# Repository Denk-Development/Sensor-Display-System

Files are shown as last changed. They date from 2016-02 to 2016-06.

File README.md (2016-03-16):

# Sensor-Display-System
A Teensy (https://www.pjrc.com/teensy/) based system for a laser show, transmitting and displaying sensor data.

In a nutshell the whole project is about showing and logging transmitted sensor data of laser show hardware. This includes among others currents, voltages, temperatures, water flow and humidity data.

For performance reasons the system uses two Teensy 3.2 micrcontrollers (72 MHz Cortex-M4) instead of the Arduino's ATmega 328. 

This is a private project.
I've developed it for Lucien Tunger (http://www.lsd-lasershowdesign.de/).

## Testing setup
The picture shows both, Sensor- and Display-Teensy. The Sensor-Teensy isn't equipped with any peripheral devices whereas the Display-Teensy is wired up with an LCD display, a real time clock module and an SD card breakout.
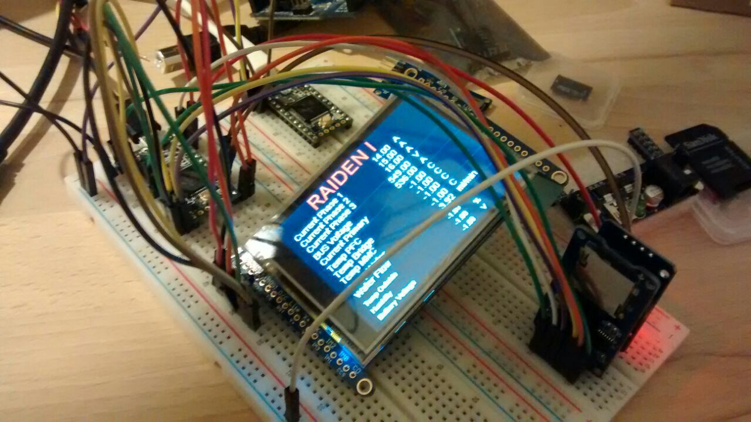
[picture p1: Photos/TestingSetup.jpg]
Testing setup image


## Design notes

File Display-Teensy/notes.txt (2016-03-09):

SD Card works only with: card.init(SPI_QUARTER_SPEED, chipSelect)
https://github.com/adafruit/Adafruit_ILI9341/blob/master/examples/spitftbitmap/spitftbitmap.ino
http://forum.arduino.cc/index.php?topic=108017.0

Use alternative time library: http://forum.arduino.cc/index.php?topic=305003.0
TimeTeensy3.ino example sketch works

Wire Real-Time Module to 3.3 V

Format SD Card not! with the Official Formatter on Mac but with the built in utilities FAT16

Arduino IDE 1.0.6

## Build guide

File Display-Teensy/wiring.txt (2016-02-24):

DISPLAY ILI9341
3-5V Vin connects to the Arduino 5V pin
GND connects to Arduino ground
CLK connects to SPI clock. On Arduino Uno/Duemilanove/328-based, thats Digital 13. On Mega's, its Digital 52 and on Leonardo/Due its ICSP-3 (See SPI Connections for more details)
MISO connects to SPI MISO. On Arduino Uno/Duemilanove/328-based, thats Digital 12. On Mega's, its Digital 50 and on Leonardo/Due its ICSP-1 (See SPI Connections for more details)
MOSI connects to SPI MOSI. On Arduino Uno/Duemilanove/328-based, thats Digital 11. On Mega's, its Digital 51 and on Leonardo/Due its ICSP-4 (See SPI Connections for more details)
CS connects to our SPI Chip Select pin. We'll be using Digital 10 but you can later change this to any pin
D/C connects to our SPI data/command select pin. We'll be using Digital 9 but you can later change this pin too.

SD CARD BREAKOUT
pin 11 = MOSI
pin 12 = MISO
pin 13 = SCK
pin 5 = CS (variable)

SENSOR TEENSY
dataLinkRX 0
dataLinkTX 1

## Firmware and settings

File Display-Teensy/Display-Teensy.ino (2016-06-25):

#include <SPI.h>

// sd card / logging
#include <SD.h>
#include <Time.h>  

// display
#include <ILI9341_t3.h>
#include <font_Arial.h>
#include <font_ArialBold.h>
#include <font_ArialItalic.h>
#include <font_ArialBoldItalic.h>

#define dataLink Serial1 // RX: 0; TX: 1

#define batteryVoltagePin A0

// display
#define TFT_DC 9
#define TFT_CS 10
#define BACKGROUND_COLOR ILI9341_BLACK
#define sensorStringsOffsetTop 30
#define sensorStringsLineHeight 15
#define unitsOffset 240
#define offsetPerHr 2

// sd card breakout
#define SD_CS 5

#define BUFFPIXEL 20

#define numberOfSensors 13
#define bytesPerSensor 4

File logFile;
char logFileName[12]; // log files have a fixed file name length of 10+1 chars ("MMDDHH.LOG")

const unsigned int millisUntilJamDetection = 50;

unsigned long lastPossibleJam = 0;
boolean jamTimerSet = false;

byte * data;
float * oldSensorValues = (float *) calloc(sizeof(float), numberOfSensors);

int dataLength, bytesAvailable, bytesAvailableAfterDelay;

long numberOfBytesAvailableLastTime = 0;

// battery voltage
int vout = 0, vin = 0;
float R1 = 47000.0, R2 = 4700.0;

// display object
ILI9341_t3 tft = ILI9341_t3(TFT_CS, TFT_DC);

String sensorNames[numberOfSensors] = { "Current Phase 1", "Current Phase 2", "Current Phase 3", "BUS Voltage", "Current Primary", "Temp PFC", "Temp Bridge", "Temp MMC", "Temp Water", "Water Flow", "Temp Outside", "Humidity", "Battery Voltage" };
String sensorUnits[numberOfSensors] = { "A", "A", "A", "V", "A", "C", "C", "C", "C", "ml/min", "C", "%", "V" };
byte sensorLineOffset[numberOfSensors] = { 0, 0, 0, offsetPerHr, offsetPerHr, 2 * offsetPerHr, 2 * offsetPerHr, 2 * offsetPerHr, 3 * offsetPerHr, 3 * offsetPerHr, 6 * offsetPerHr, 6 * offsetPerHr, 6 * offsetPerHr };

void setup() {
  pinMode(batteryVoltagePin, INPUT);
  Serial.begin(9600);
  
  // start tft
  tft.begin();
  tft.setRotation(3);
  tft.fillScreen(BACKGROUND_COLOR);
  
  // start sd card
  Serial.print("Initializing SD card...");
  if (!SD.begin(SD_CS, SPI_QUARTER_SPEED)) {
    Serial.println("SD card failed");
  }
  Serial.println("SD card ok");

  // draw logo
  bmpDraw("logo.bmp", 0, 0);
  
  Serial.println("showing logo");
  
  delay(5000); // show logo
  
  
  // initialize time module 
  // set the Time library to use Teensy 3.0's RTC to keep time
  setSyncProvider(getTeensy3Time);
  delay(100);
  if (timeStatus() != timeSet) {
    Serial.println("Unable to sync with the RTC");
  } else {
    Serial.println("RTC has set the system time");
  }
  
  
  Serial.println("showing sensor data");
  tft.fillScreen(BACKGROUND_COLOR);
  
  tft.setCursor(70, 5);
  tft.setFont(Arial_24);
  tft.setTextColor(rgb2col(255,0,0));
  tft.print("RAIDEN I");
  
  
  // print sensor names
  tft.setFont(Arial_10);
  tft.setTextColor(rgb2col(255,255,255));
  for (int i = 0; i < numberOfSensors; i++) {    
    if (i == 10) {
      tft.setFont(Arial_8);
    }
    
    int yOffset =  5 + sensorStringsOffsetTop + sensorStringsLineHeight * i + sensorLineOffset[i];
    tft.setCursor(15, yOffset);
    tft.print(sensorNames[i]);
    tft.setCursor(unitsOffset, yOffset);
    tft.print(sensorUnits[i]);
  }
  
  // draw horizontal lines
  uint16_t hLineColor = rgb2col(25,25,25);
  tft.drawFastHLine(0, 5 + sensorStringsOffsetTop + 3 * sensorStringsLineHeight - 3 + 1 * offsetPerHr, 320, hLineColor);
  tft.drawFastHLine(0, 5 + sensorStringsOffsetTop + 5 * sensorStringsLineHeight - 3 + 2 * offsetPerHr, 320, hLineColor);
  tft.drawFastHLine(0, 5 + sensorStringsOffsetTop + 8 * sensorStringsLineHeight - 3 + 3 * offsetPerHr, 320, hLineColor);
  tft.drawFastHLine(0, 5 + sensorStringsOffsetTop + 10 * sensorStringsLineHeight - 3 + 4 * offsetPerHr, 320, hLineColor);
  
  dataLength = numberOfSensors * bytesPerSensor;
  data = (byte *) malloc(sizeof(byte) * dataLength);
  
  // create log file
  String tmp = getLogFileName();
  logFileName[tmp.length()+1];
  tmp.toCharArray(logFileName, sizeof(logFileName));
  Serial.println(tmp.length());
  Serial.println(tmp);
  Serial.println(logFileName);
  logFile = SD.open(logFileName, FILE_WRITE);
  logFile.close();
  
  // check if the log file has been created successfully
  if (SD.exists(logFileName)) {
    Serial.println("log file created");
  } else {
    Serial.println("couldn't create log file");
  }
  
  
  // serial connection to sensor arduino
  dataLink.begin(58824); // Arduino 57600 is actually 58824 (https://www.pjrc.com/teensy/td_uart.html)
  // baud rates 300, 600, 1200, 2400, 4800, 9600, 14400, 19200, 28800, 31250, 38400, 57600, 115200
}

void loop() {
  // time module
  if (jamTimerSet && lastPossibleJam < millis() - millisUntilJamDetection) {
    jamTimerSet = false;
    flushDataLinkBuffer();
    Serial.println("flushed");
  }
  
  
  // check if data is currently incoming
  if (numberOfBytesAvailableLastTime != dataLink.available()) {
    jamTimerSet = false;
    Serial.println("jam timer set");
  }
  
  if (dataLink.available() > 0 && dataLink.available() % dataLength == 0) {
    jamTimerSet = false;
    
    Serial.println("data incoming");
    
    dataLink.readBytes((char *)data, dataLength);
    
    // open log file
    logFile = SD.open(logFileName, FILE_WRITE);
    logFile.print(getTimeString()); // log time
    
    tft.setFont(Arial_10);
    for (int i = 0;  i < numberOfSensors; i++) {    
      if (i == 10) {
        tft.setFont(Arial_8);
      }
      
      float * sensorValue = (float *) & data[i * bytesPerSensor];
      float val = * sensorValue;
      
      if (i == 12) { // battery voltage
        val = getBatteryVoltage();
      }
      
      logFile.print(",");
      logFile.print(val);
      
      Serial.println("Sensor " + String(i) + ": " + String(val));
      
      // write only to the screen when values have changed
      if (oldSensorValues[i] != val) {
        String valString = floatToDisplayString(val);
        byte valStringLength = valString.length();
        byte minusSignOffset = (valString.charAt(0) == '-') ? 4 : 0;
        byte cursorY = 5 + sensorStringsOffsetTop + sensorStringsLineHeight * i + sensorLineOffset[i];
        tft.setCursor(5 + 160 + (8 - valStringLength) * 9 + minusSignOffset, cursorY);
        
        // hide old value by drawing a rectangle (x, y, width, height)
        tft.fillRect(160, cursorY, 75, sensorStringsLineHeight - 4, BACKGROUND_COLOR); // clear row
        tft.print(valString);
        
        oldSensorValues[i] = val;
      }
    }
    
    // log file end line
    logFile.println();
    logFile.close(); // save changes
  }
  
  // possibly invalid data in the buffer
  else if (!jamTimerSet && dataLink.available() != 0) {
    lastPossibleJam = millis();
    jamTimerSet = true;
  }
}

void flushDataLinkBuffer() {
  Serial.println("flushed");
  while (dataLink.available()) {
    dataLink.read();
  }
}

String floatToDisplayString(float f) {
  String s = String(f);
  // add leading spaces
  /*while (s.length() < 7) {
    s = " " + s;
  }*/
  return s; 
}


uint16_t rgb2col(uint8_t r, uint8_t g, uint8_t b) {
  return ((r & 0xF8) << 8) | ((g & 0xFC) << 3) | (b >> 3);
}


// time module code

String getTimeString() {
  return addLeadingZeros(year(), 4) + "." + addLeadingZeros(month(), 2) + "." + addLeadingZeros(day(), 2) + " " + addLeadingZeros(hour(), 2) + ":" + addLeadingZeros(minute(), 2) + ":" + addLeadingZeros(second(), 2);
}

String getLogFileName() {
  return addLeadingZeros(month(), 2) + addLeadingZeros(day(), 2) + addLeadingZeros(hour(), 2) + ".LOG";  
}

time_t getTeensy3Time()
{
  return Teensy3Clock.get();
}

/*  code to process time sync messages from the serial port   */
#define TIME_HEADER  "T"   // Header tag for serial time sync message

unsigned long processSyncMessage() {
  unsigned long pctime = 0L;
  const unsigned long DEFAULT_TIME = 1357041600; // Jan 1 2013 

  if(Serial.find(TIME_HEADER)) {
     pctime = Serial.parseInt();
     return pctime;
     if( pctime < DEFAULT_TIME) { // check the value is a valid time (greater than Jan 1 2013)
       pctime = 0L; // return 0 to indicate that the time is not valid
     }
  }
  return pctime;
}

void printDigits(int digits){
  // utility function for digital clock display: prints preceding colon and leading 0
  Serial.print(":");
  if(digits < 10)
    Serial.print('0');
  Serial.print(digits);
}

String addLeadingZeros(int x, int digits) {
  String str = String(x);
  while (str.length() < digits) {
    str = '0' + str;
  }
  return str;
}

// battery voltage
long readVcc() {
  long result;
  ADMUX = _BV(REFS0) | _BV(MUX3) | _BV(MUX2) | _BV(MUX1);
  delay(2);
  ADCSRA |= _BV(ADSC);
  while (bit_is_set(ADCSRA,ADSC));
  result = ADCL;
  result |= ADCH<<8;
  result = 1126400L / result;
  return result;
}

int getBatteryVoltage() {
  vout = (analogRead(batteryVoltagePin) * readVcc() / 1000) / 1024.0;
  vin = vout / (R2/(R1+R2));
  return vin;
}



// draw bitmap code


// This function opens a Windows Bitmap (BMP) file and
// displays it at the given coordinates.  It's sped up
// by reading many pixels worth of data at a time
// (rather than pixel by pixel).  Increasing the buffer
// size takes more of the Arduino's precious RAM but
// makes loading a little faster.  20 pixels seems a
// good balance.

#define BUFFPIXEL 20

void bmpDraw(char *filename, uint8_t x, uint16_t y) {

  File     bmpFile;
  int      bmpWidth, bmpHeight;   // W+H in pixels
  uint8_t  bmpDepth;              // Bit depth (currently must be 24)
  uint32_t bmpImageoffset;        // Start of image data in file
  uint32_t rowSize;               // Not always = bmpWidth; may have padding
  uint8_t  sdbuffer[3*BUFFPIXEL]; // pixel buffer (R+G+B per pixel)
  uint8_t  buffidx = sizeof(sdbuffer); // Current position in sdbuffer
  boolean  goodBmp = false;       // Set to true on valid header parse
  boolean  flip    = true;        // BMP is stored bottom-to-top
  int      w, h, row, col;
  uint8_t  r, g, b;
  uint32_t pos = 0, startTime = millis();

  if((x >= tft.width()) || (y >= tft.height())) return;

  Serial.println();
  Serial.print(F("Loading image '"));
  Serial.print(filename);
  Serial.println('\'');

  // Open requested file on SD card
  if ((bmpFile = SD.open(filename)) == NULL) {
    Serial.print(F("file not found"));
    return;
  }

  // Parse BMP header
  if(read16(bmpFile) == 0x4D42) { // BMP signature
    Serial.print(F("File size: ")); Serial.println(read32(bmpFile));
    (void)read32(bmpFile); // Read & ignore creator bytes
    bmpImageoffset = read32(bmpFile); // Start of image data
    Serial.print(F("Image Offset: ")); Serial.println(bmpImageoffset, DEC);
    // Read DIB header
    Serial.print(F("Header size: ")); Serial.println(read32(bmpFile));
    bmpWidth  = read32(bmpFile);
    bmpHeight = read32(bmpFile);
    if(read16(bmpFile) == 1) { // # planes -- must be '1'
      bmpDepth = read16(bmpFile); // bits per pixel
      Serial.print(F("Bit Depth: ")); Serial.println(bmpDepth);
      if((bmpDepth == 24) && (read32(bmpFile) == 0)) { // 0 = uncompressed

        goodBmp = true; // Supported BMP format -- proceed!
        Serial.print(F("Image size: "));
        Serial.print(bmpWidth);
        Serial.print('x');
        Serial.println(bmpHeight);

        // BMP rows are padded (if needed) to 4-byte boundary
        rowSize = (bmpWidth * 3 + 3) & ~3;

        // If bmpHeight is negative, image is in top-down order.
        // This is not canon but has been observed in the wild.
        if(bmpHeight < 0) {
          bmpHeight = -bmpHeight;
          flip      = false;
        }

        // Crop area to be loaded
        w = bmpWidth;
        h = bmpHeight;
        if((x+w-1) >= tft.width())  w = tft.width()  - x;
        if((y+h-1) >= tft.height()) h = tft.height() - y;

        // Set TFT address window to clipped image bounds
        tft.setAddrWindow(x, y, x+w-1, y+h-1);

        for (row=0; row<h; row++) { // For each scanline...

          // Seek to start of scan line.  It might seem labor-
          // intensive to be doing this on every line, but this
          // method covers a lot of gritty details like cropping
          // and scanline padding.  Also, the seek only takes
          // place if the file position actually needs to change
          // (avoids a lot of cluster math in SD library).
          if(flip) // Bitmap is stored bottom-to-top order (normal BMP)
            pos = bmpImageoffset + (bmpHeight - 1 - row) * rowSize;
          else     // Bitmap is stored top-to-bottom
            pos = bmpImageoffset + row * rowSize;
          if(bmpFile.position() != pos) { // Need seek?
            bmpFile.seek(pos);
            buffidx = sizeof(sdbuffer); // Force buffer reload
          }

          for (col=0; col<w; col++) { // For each pixel...
            // Time to read more pixel data?
            if (buffidx >= sizeof(sdbuffer)) { // Indeed
              bmpFile.read(sdbuffer, sizeof(sdbuffer));
              buffidx = 0; // Set index to beginning
            }

            // Convert pixel from BMP to TFT format, push to display
            b = sdbuffer[buffidx++];
            g = sdbuffer[buffidx++];
            r = sdbuffer[buffidx++];
            tft.pushColor(tft.color565(r,g,b));
          } // end pixel
        } // end scanline
        Serial.print(F("Loaded in "));
        Serial.print(millis() - startTime);
        Serial.println(" ms");
      } // end goodBmp
    }
  }

  bmpFile.close();
  if(!goodBmp) Serial.println(F("BMP format not recognized."));
}

// These read 16- and 32-bit types from the SD card file.
// BMP data is stored little-endian, Arduino is little-endian too.
// May need to reverse subscript order if porting elsewhere.

uint16_t read16(File &f) {
  uint16_t result;
  ((uint8_t *)&result)[0] = f.read(); // LSB
  ((uint8_t *)&result)[1] = f.read(); // MSB
  return result;
}

uint32_t read32(File &f) {
  uint32_t result;
  ((uint8_t *)&result)[0] = f.read(); // LSB
  ((uint8_t *)&result)[1] = f.read();
  ((uint8_t *)&result)[2] = f.read();
  ((uint8_t *)&result)[3] = f.read(); // MSB
  return result;
}

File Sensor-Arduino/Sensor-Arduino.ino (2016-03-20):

#include <SoftwareSerial.h>
#include <Wire.h>
#include <Adafruit_MCP9808.h>
#include <Adafruit_HTU21DF.h>

// pinning
// Serial TX Pin 0
// Serial RX Pin 1
#define flowSensorPin 2
#define dataLinkRX 3
#define dataLinkTX 4

#define currentPhase1Pin A0
#define currentPhase2Pin A1
#define currentPhase3Pin A2
// #define flowCurrrentPin A5 
#define busVoltagePin A5

#define flowSensorInterrupt 0  // 0 = digital pin 2

#define transmissionInterval 300

const byte numberOfSensors = 13, bytesPerSensor = 4;

byte * data, * sensorValue;

int dataLength;

unsigned long lastTransmission = 0;

SoftwareSerial dataLink(dataLinkRX, dataLinkTX); // RX, TX

// sensors
Adafruit_MCP9808 tempsensor1 = Adafruit_MCP9808();
Adafruit_MCP9808 tempsensor2 = Adafruit_MCP9808();
Adafruit_MCP9808 tempsensor3 = Adafruit_MCP9808();
Adafruit_MCP9808 tempsensor4 = Adafruit_MCP9808();

Adafruit_HTU21DF htu = Adafruit_HTU21DF();

// AC current (3 sensors, A0, A1, A2)
float gfLineVoltage = 230.0f; // current in V
float gfACS712_Factor = 60.0f; // 50.0f for 20A sensor, 75.76f for 30A sensor; 27.03f for 5A sensor
unsigned long gulSamplePeriod_us = 20000; // 50ms is 10 cycles at 50Hz and 12 cycles at 60Hz
int giADCOffset[3] = { 512, 512, 512 }; // offset for "0" Sensor WSC1800

// flow sensor
// The hall-effect flow sensor outputs approximately 4.5 pulses per second per
// litre/minute of flow.
float calibrationFactor = 4.5;
volatile byte pulseCount;  
float flowRate, flowSensorOutput;
unsigned int flowMilliLitres;
unsigned long totalMilliLitres;
unsigned long oldTimeFlowSensor;
// end flow sensor

void setup() {
  dataLink.begin(57600);
  // baud rates 300, 600, 1200, 2400, 4800, 9600, 14400, 19200, 28800, 31250, 38400, 57600, 115200
    
  dataLength = numberOfSensors * bytesPerSensor;
  data = (byte *) malloc(sizeof(byte) * dataLength);
  sensorValue = (byte *) malloc(sizeof(byte) * bytesPerSensor);
  
  for (int i = 0; i < dataLength; i++) {
    data[i] = 0;
  }
  
  
  // temp sensors
  tempsensor1.begin(0x18);
  tempsensor2.begin(0x19);
  tempsensor3.begin(0x1A);
  tempsensor4.begin(0x1B);
  
  htu.begin();
  
  // flow sensor
  pinMode(flowSensorPin, INPUT);
  digitalWrite(flowSensorPin, HIGH);

  pulseCount = 0;
  flowRate = 0.0;
  flowMilliLitres = 0;
  totalMilliLitres = 0;
  oldTimeFlowSensor = 0;

  // The Hall-effect sensor is connected to pin 2 which uses interrupt 0.
  // Configured to trigger on a FALLING state change (transition from HIGH
  // state to LOW state)
  attachInterrupt(flowSensorInterrupt, pulseCounter, FALLING);
}

void loop() {
  if ((millis() - lastTransmission) > transmissionInterval && readSensorData()) {
    lastTransmission = millis();
    // data has changed
    dataLink.write(data, dataLength);
  }
  
  if((millis() - oldTimeFlowSensor) > 1000)    // Only process counters once per second
  { 
    // Disable the interrupt while calculating flow rate and sending the value to
    // the host
    detachInterrupt(flowSensorInterrupt);
        
    // Because this loop may not complete in exactly 1 second intervals we calculate
    // the number of milliseconds that have passed since the last execution and use
    // that to scale the output. We also apply the calibrationFactor to scale the output
    // based on the number of pulses per second per units of measure (litres/minute in
    // this case) coming from the sensor.
    flowRate = ((1000.0 / (millis() - oldTimeFlowSensor)) * pulseCount) / calibrationFactor;
    
    // Note the time this processing pass was executed. Note that because we've
    // disabled interrupts the millis() function won't actually be incrementing right
    // at this point, but it will still return the value it was set to just before
    // interrupts went away.
    oldTimeFlowSensor = millis();
    
    // Divide the flow rate in litres/minute by 60 to determine how many litres have
    // passed through the sensor in this 1 second interval, then multiply by 1000 to
    // convert to millilitres.
    flowMilliLitres = (flowRate / 60) * 1000;
    
    // Add the millilitres passed in this second to the cumulative total
    totalMilliLitres += flowMilliLitres;
    
    // sensor value variable
    flowSensorOutput = (flowRate - int(flowRate)) * 10;

    // Reset the pulse counter so we can start incrementing again
    pulseCount = 0;
    
    // Enable the interrupt again now that we've finished sending output
    attachInterrupt(flowSensorInterrupt, pulseCounter, FALLING);
  }
}

boolean readSensorData() {
  boolean changeDetected = false;
  // iterate through sensors
  for (int sensor = 0; sensor < numberOfSensors; sensor++) {
    // read the actual value
    float sensorValue;
    switch(sensor) {
      case 0:
        // Current Phase 1
        sensorValue = measureCurrent(currentPhase1Pin);
        break;
      case 1:
        // Current Phase 2
        sensorValue = measureCurrent(currentPhase2Pin);
        break;
      case 2:
        // Current Phase 3
        sensorValue = measureCurrent(currentPhase3Pin);
        break;
      case 3:
        // BUS Spannung
        sensorValue = (float)analogRead(busVoltagePin);
        break;
      case 4:
        // Current Primary
        sensorValue = 0; // (float)analogRead(flowCurrrentPin);
        break;
      case 5:
        // Temp PFC
        sensorValue = tempsensor2.readTempC();
        break;
      case 6:
        // Temp Bridge
        sensorValue = tempsensor1.readTempC();
        break;
      case 7:
        // Temp MMC
        sensorValue = tempsensor3.readTempC();
        break;
      case 8:
        // Temp Water
        sensorValue = tempsensor4.readTempC();
        break;
      case 9:
        // Water Flow
        sensorValue = flowSensorOutput;
        break;
      case 10:
        // HTU21D-F
        sensorValue = htu.readTemperature();
        break;
      case 11:
        // HTU21D-F
        sensorValue = htu.readHumidity();
        break;
      default: 
        sensorValue = -1.0f;
        break;
    }
    
    // byte pointer to the sensor value
    byte * sensorValuePointer = (byte *) &sensorValue;
    
    // read all bytes of the sensor value into the data array
    for (int sensorByte = 0; sensorByte < bytesPerSensor; sensorByte++) {
      if (* (data + sensor * bytesPerSensor + sensorByte) != * (sensorValuePointer + sensorByte)) {
        changeDetected = true;
        * (data + sensor * bytesPerSensor + sensorByte) = * (sensorValuePointer + sensorByte);
      }
    }
  }
  
  return changeDetected;
}

/*
Interrupt Service Routine Flow Sensor
 */
void pulseCounter()
{
  // Increment the pulse counter
  pulseCount++;
}
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

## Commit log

2016-01-08 Performance optimisation
    Improved the performance of rendering the sensor values.
2016-01-09 Added flow sensor
    Liquid flow rate sensor
2016-01-09 Added HTU21DF sensor
    Humidity and temperature sensor
2016-01-10 Added htu temperature
2016-02-12 Added display Arduino wiring information
2016-02-24 Display-Teensy
    Display-Arduino code is deprecated and replaced by Display-Teensy
    Fixed typo in Sensor-Arduino.ino
    [Display-Teensy.ino, Sensor-Arduino.ino]
2016-03-09 Added more sensors, units and restructured display
2016-03-09 Added more sensors (debugging mode)
2016-03-09 Re-enabled sensors
2016-03-09 Added Teensy notes and removed deprecated code
2016-03-13 Important baud rate update
    https://www.pjrc.com/teensy/td_uart.html
    "Arduino creates the same baud rates as Teensyduino, except at 57600, where Arduino's error is +2.12%. When communicating with an Arduino board, the combined +2.12% and -0.79% error is too much. Successful communication with Arduino requires 58824 baud."
    [Display-Teensy.ino]
2016-03-15 AC Current Measurement
2016-03-15 Bugfixes and implementation in Sensor-Arduino code
    [Current-Measurement.ino, Sensor-Arduino.ino]
2016-03-16 Sensor-Teensy instead of Arduino
2016-03-16 Battery Voltage
2016-03-17 Measure current function
2016-03-19 Sensor-Arduino with analog multiplexer
2016-03-20 Version 1.0
    Removed analog multiplexer for complexity reasons and commented flow
    current out.
2016-04-17 Analog multiplexer notes and schematics draft
    [Schmeatics.fzz]
